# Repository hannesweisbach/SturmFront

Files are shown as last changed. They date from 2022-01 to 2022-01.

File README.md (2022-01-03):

# SturmFront

SturmFront is a DIY fan-controller for indoor sports, which adjusts fan speed according to your current heart rate.

Commercially available is the Wahoo® KICKR Headwind, which has an integrated fan and regulates fan speed according to your power output. Keith Wakeham developed an open-source DIY fan controller named [Maelstom](https://github.com/kwakeham/Maelstrom). Maelstrom also adjusts fan speed according to your power output.

I developed SturmFront independently. A project description is also available: [https://hannesweisbach.github.io/SturmFront/](https://hannesweisbach.github.io/SturmFront/)

## Software used

I used KiCAD as EDA-tool. The controller is based on the Nordic Semiconductor [NRF52832 SoC](https://www.nordicsemi.com/products/nrf52832). I used the [NRF5 SDK 17.1.0](https://www.nordicsemi.com/Products/Development-software/nrf5-sdk/download) in conjuction with the [S332 softdevice](https://www.nordicsemi.com/Products/Development-software/s332-ant) to provide ANT+ and BLE connectivity.

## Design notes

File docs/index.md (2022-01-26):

## SturmFront

SturmFront is a DIY fan-controller for indoor sports, which adjusts fan speed according to your current heart rate.

I use while riding Zwift. The advantages:

* **Never forget to turn on your fan.** SturmFront turns on your fan automatically.
* **Never freeze your butt off during warming up.** SturmFront adjusts the fan speed to your current heart rate. Low heart rate means the fan spins slowly or is even off.
* **Auto-adjusts during the ride.** No weird acrobatics during a ride or race to adjust your fan speed. Your fan already has adjustable speed, but it is almost out of reach? You have to lean awkwardly towards your fan, risking falling off your bike?
* **Never freeze during cooldown.** Ride, race or workout is over? Especially in autumn or winter I was freezing if my fan was still going full blast.

## Alternatives

I developed SturmFront as a low-cost, DIY-version of the well-known Wahoo® KICKR Headwind. In contrast to the KICKR Headwind, SturmFront does not have an integrated fan, but can be thought of like a smart plug, but instead of WiFi it uses ANT+ and instead of simply on/off-control SturmFront offers adjustable power output. This allows SturmFront to turn any fan into a smart fan.
Keith Wakeham developed also a DIY fan controller named [Maelstom](https://github.com/kwakeham/Maelstrom).

## Function

A short, probably not complete description of how SturmFront works.

### Hardware

As basis for SturmFront I used a second-hand WiFi-enabled smart socket from the local classifieds. It cost me only 2,50€ and I got a living room suitable enclosure as well as the proper power socket connectors:

<p align="middle">
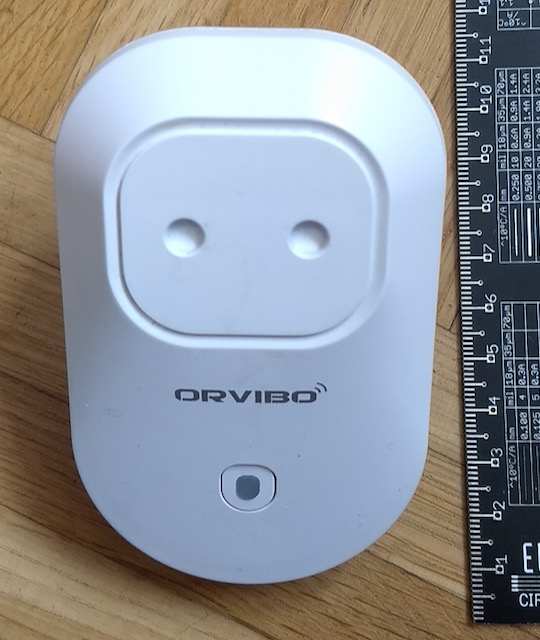
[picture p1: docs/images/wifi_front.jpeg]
Front view of wifi smart socket with CEE 7/4 plug and CEE 7/16 socket.
  
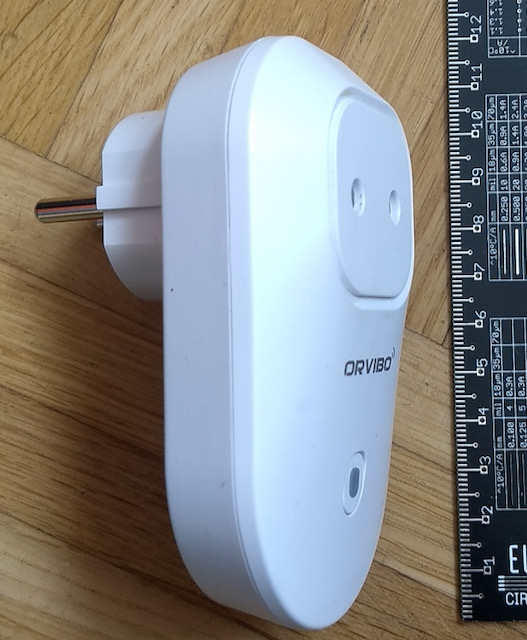
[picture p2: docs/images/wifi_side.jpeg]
Side view of wifi smark socket with CEE 7/4 plug and CEE 7/16 socket.
  
</p>

I also re-used the components from the power supply. I couldn't re-use the SoC and/or WiFi chip, beacuse I needed ANT+ and Bluetooth connectivity. The electro-mechanical relay was also not of any use to me, because I needed phase control to be able to adjust the fan's speed.

The whole circuit consists of a just a few building blocks:
* an SSR with a snubber circuit
* a module with an NRF82832 SoC with ANT+/BLE connectivity
* a zero-crossing circuit to help the NRF control the SSR
* power supply for the NRF

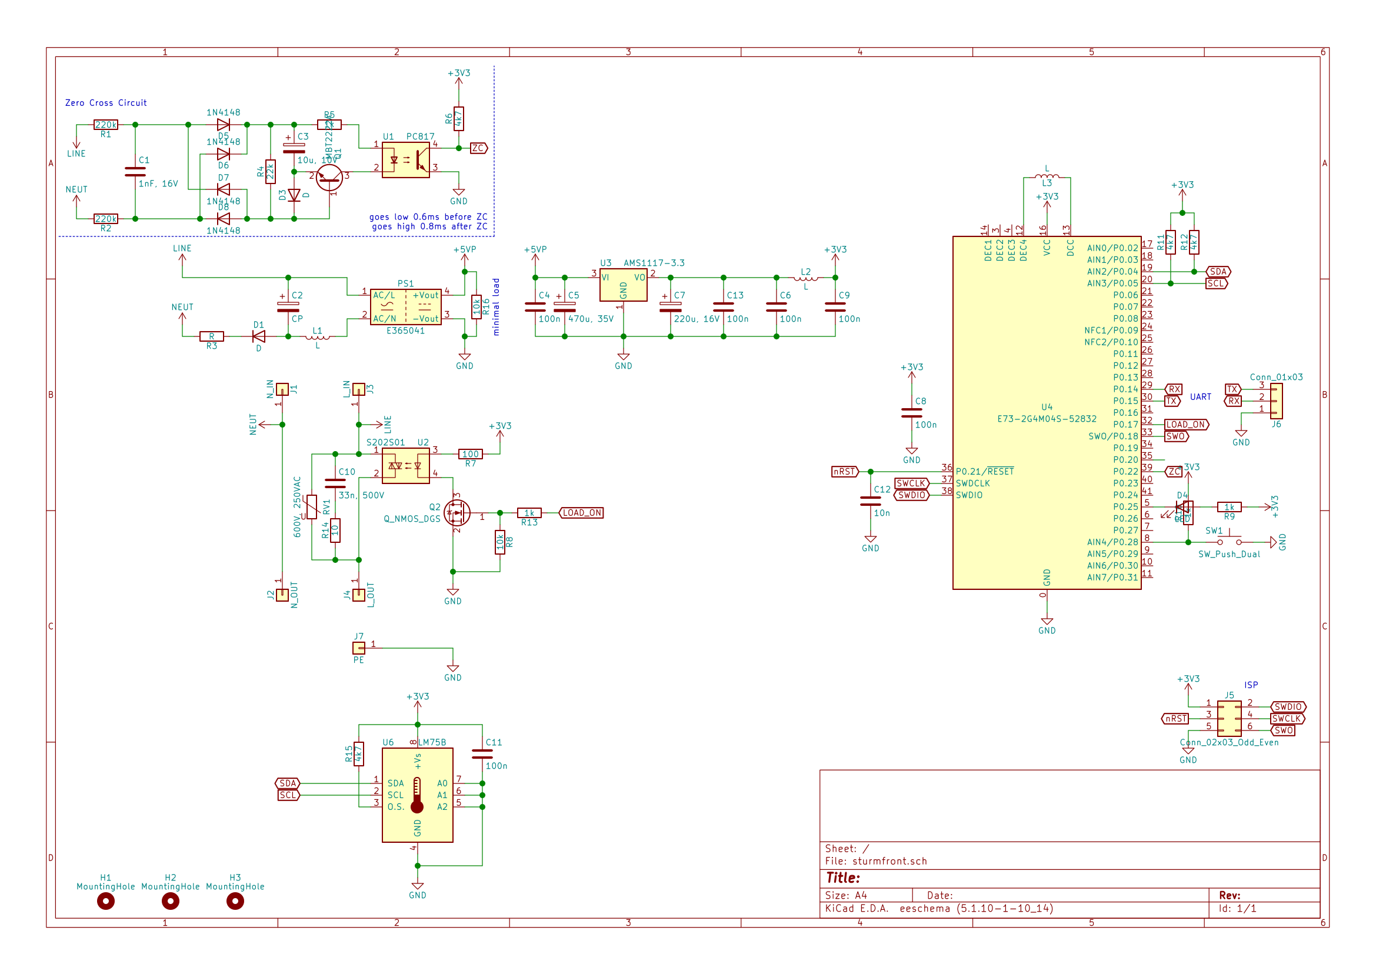
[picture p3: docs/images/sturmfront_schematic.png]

There is a PDF of the schematic under [EDA/sturmfront.pdf](https://github.com/hannesweisbach/SturmFront/blob/master/EDA/sturmfront.pdf).

Both power supply as well as zero cross detection are isolated, which makes this design relatively expensive, but also easier to work with, develop and debug. The Isolated DC/DC-converter as well as the 3.3V LDO are re-used, although I added a PI-filter to the LDO output and the NRF-module is not the best, layout-wise. I also reserved space for an LM75 temperature sensor, but I used to on-chip sensor of the NRF. I figured since the SoC spends most of the time in powerdown anyway the difference from ambient to junction should not be that much (~2K).

Before ordering a manufactured PCB, I isolation-milled an engineering prototype:

<p align="middle">
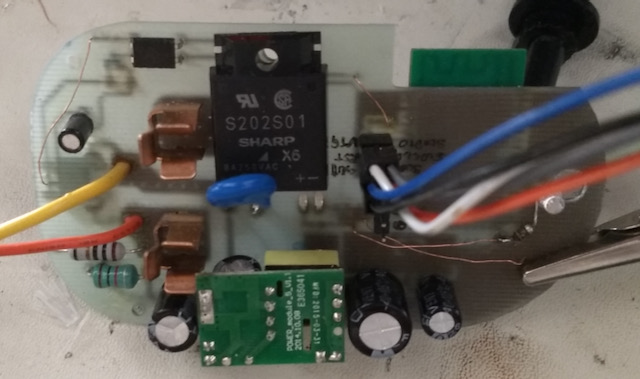
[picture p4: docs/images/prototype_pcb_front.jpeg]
  
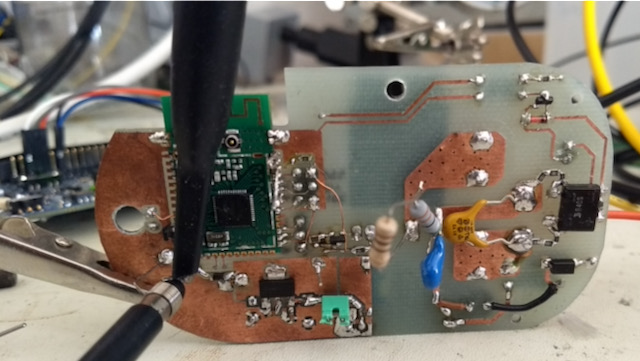
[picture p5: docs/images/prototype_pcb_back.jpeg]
  
</p>

Since the PCB is oddly-shaped with large radii all around plus a button, LED and screw holes all of whose locations have to match with the case, having a prototype allowed me to check all dimensions before ordering as well as to check if all components would still fit in the case height-wise. I was also able to check for errors and improvements in the PCB design. Lastly, I was able to polish the firmware before the final boards arrived.

<p align="middle">
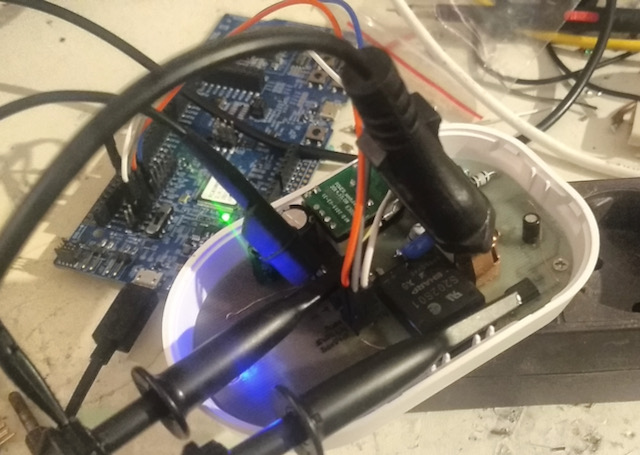
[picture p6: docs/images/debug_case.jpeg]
Isolation milled engineering prototype PCB in smart wifi plug case with oscilloscope probes and debug adapter attached.
  
</p>

Note that the outlet in the picture is not connected to mains but to an isolation transformer for testing.

Making a prototype turned out to be a good decision, since I found multiple errors in the PCB which I had fixed for the final, professionally manufactured PCB. I still managed to sneak a few issues in the final PCB. For example, the silkscreen of the pinout labels of the ISP-connector are hidden underneath the SSR. 😅

<p align="middle">
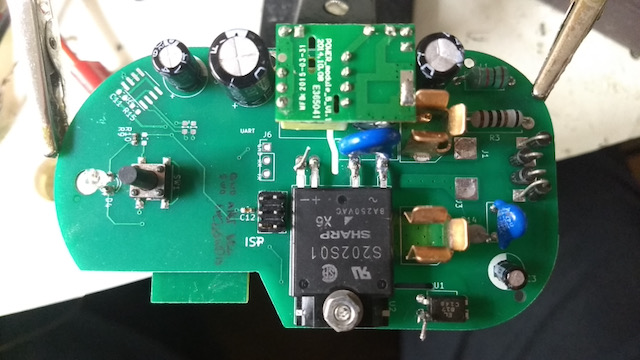
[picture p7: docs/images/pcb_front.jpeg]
  
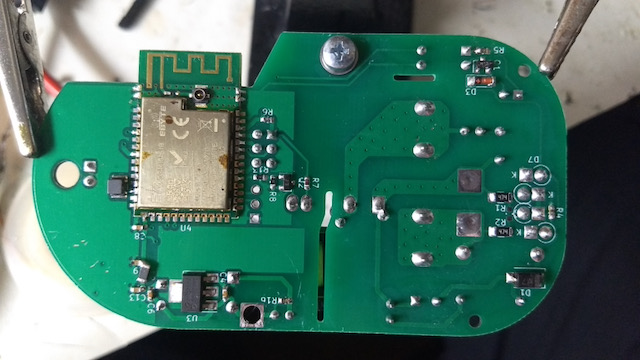
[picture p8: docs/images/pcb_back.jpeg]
  
</p>

### Software

During development and testing of SturmFront it soon became obvious to me that speed control linearly proportinal to heart rate is insufficient.
- First, I added a temperature input to the control software to compensate for colder air temperatures in winter and/or when my window is open. Temperature can be adjusted 5˚K intervals.
- Second, instead of linearly mapping the heart rate to control the SSR, fan speed can now be adjusted 5 bpm increments.

SturmFront uses bilinear mapping to interpolate between 5˚K and 5 bpm values.

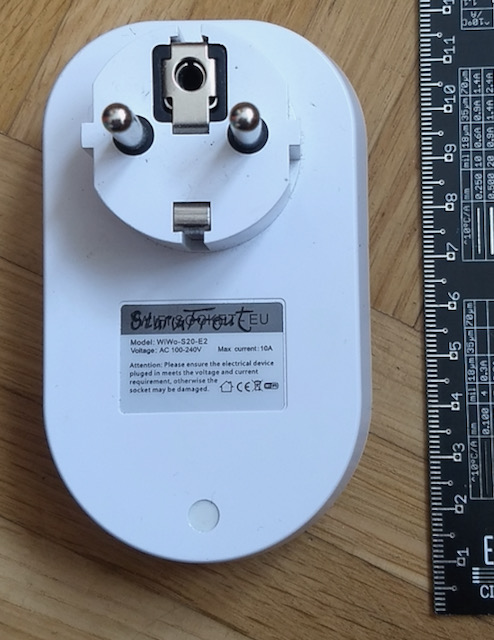
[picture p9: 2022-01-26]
docs/images/wifi_back.jpeg

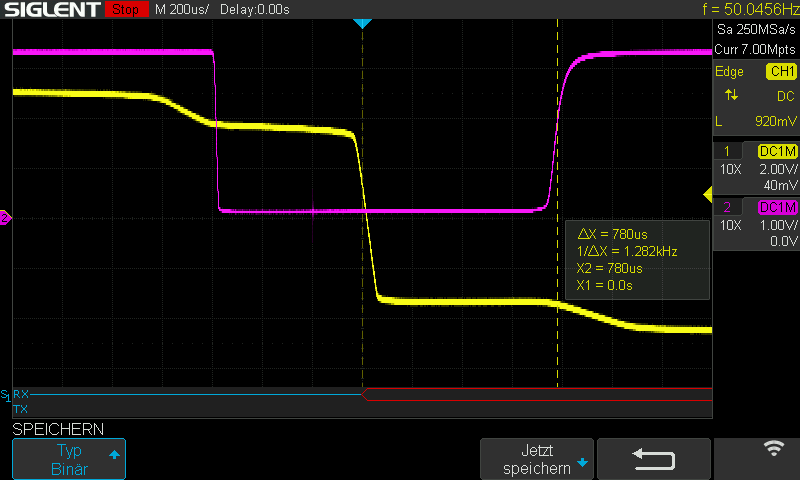
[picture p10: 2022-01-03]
EDA/ZeroCross-2.png

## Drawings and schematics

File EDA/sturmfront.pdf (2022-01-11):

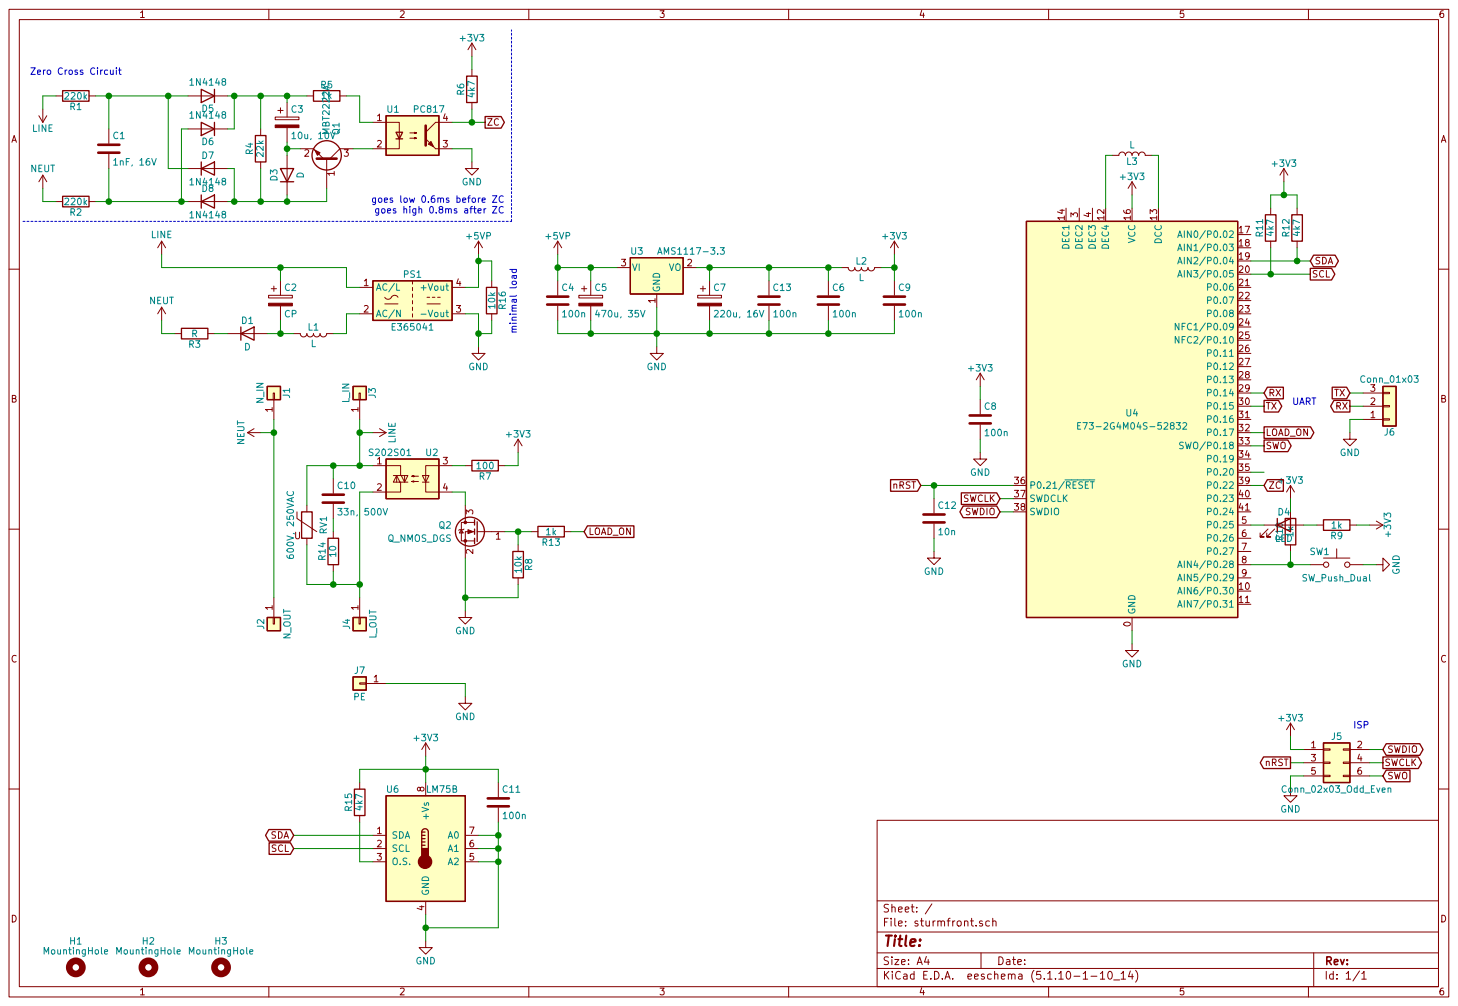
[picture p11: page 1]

goes low 0.6ms before ZC
goes high 0.8ms after ZC minimal load

3 P0.15 30 P0.16 31 P0.17 32 SWO/P0.18 33 P0.19 34 P0.20 35 P0.21/RESET 36 SWDCLK 37 SWDIO 38 P0.22 39 DEC3

Id: 1/1 Title: File: sturmfront.sch Sheet: /

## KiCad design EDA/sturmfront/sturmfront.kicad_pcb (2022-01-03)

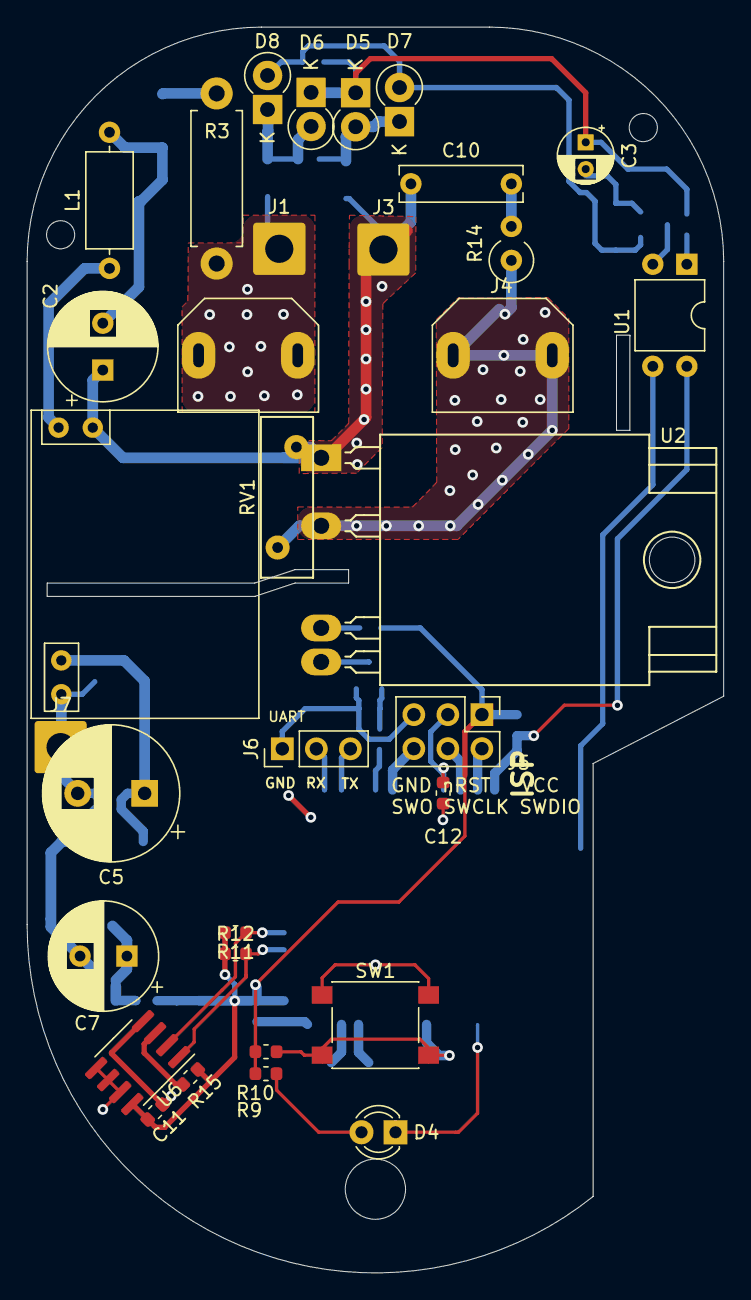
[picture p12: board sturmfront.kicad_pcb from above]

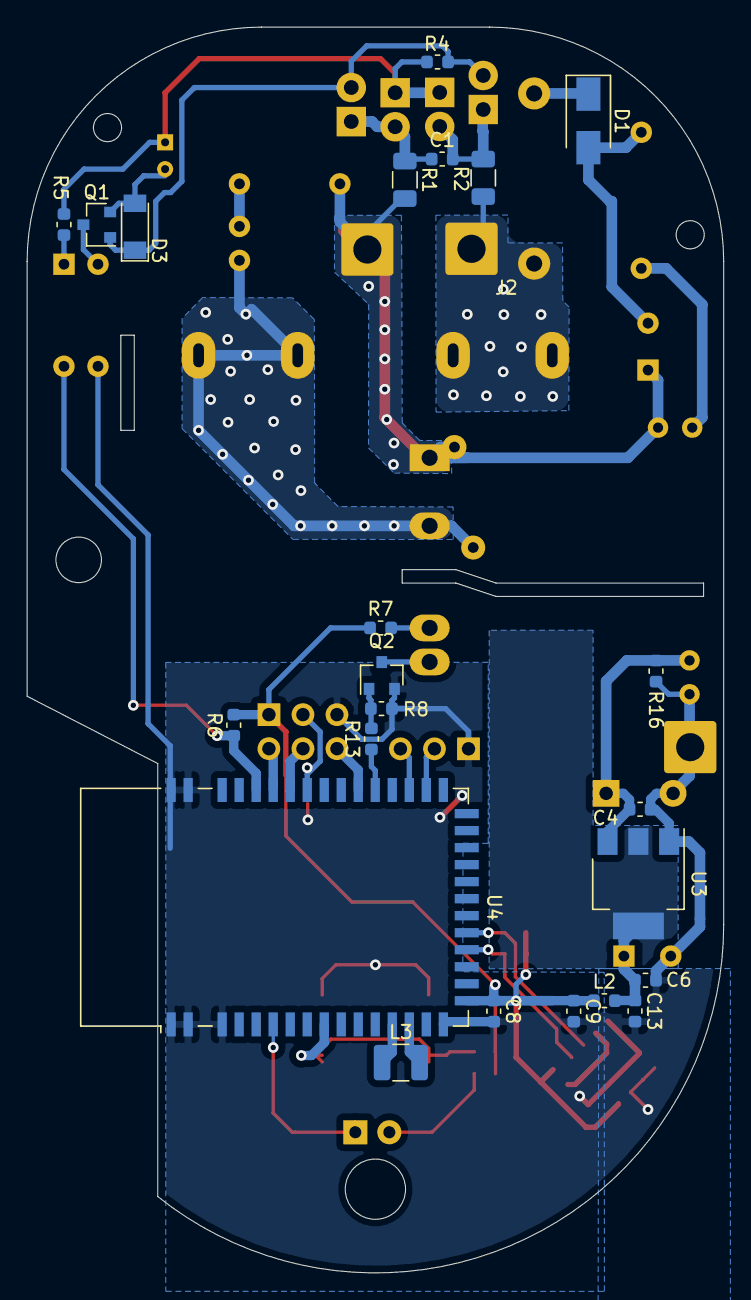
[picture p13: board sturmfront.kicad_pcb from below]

Board: 2 copper layers, 52.0 x 93.0 mm, 59 parts (23 on the bottom side), 37 nets.

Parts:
C1: 1nF, 16V; C_0603_1608Metric
C2: CP; CP_Radial_D8.0mm_P3.50mm
C3: 10u, 10V; CP_Radial_D4.0mm_P2.00mm
C4, C6, C8, C9, C11, C13: 100n; C_0603_1608Metric
C5: 470u, 35V; CP_Radial_D10.0mm_P5.00mm
C7: 220u, 16V; CP_Radial_D8.0mm_P3.50mm
C10: 33n, 500V; C_Rect_L9.0mm_W2.5mm_P7.50mm_MKT
C12: 10n; C_0603_1608Metric
D1: D; D_SMA
D3: D; D_MiniMELF
D4: LED; LED_D3.0mm_Clear
D5, D6, D7, D8: 1N4148; D_DO-41_SOD81_P2.54mm_Vertical_KathodeUp
H1: MountingHole; MountingHole_4.5mm
H2, H3: MountingHole; MountingHole_2.1mm
J1: N_IN; SolderWire-1.5sqmm_1x01_D1.7mm_OD3.9mm
J2: N_OUT; PowerSocket
J3: L_IN; SolderWire-1.5sqmm_1x01_D1.7mm_OD3.9mm
J4: L_OUT; PowerSocket
J5: Conn_02x03_Odd_Even; PinHeader_2x03_P2.54mm_Vertical
J6: Conn_01x03; PinHeader_1x03_P2.54mm_Vertical
J7: PE; SolderWire-1.5sqmm_1x01_D1.7mm_OD3.9mm
L1: L; L_Axial_L7.0mm_D3.3mm_P10.16mm_Horizontal_Fastron_MICC
L2: L; L_0603_1608Metric
L3: L; L_1210_3225Metric
PS1: E365041; DCDC
Q1: MBT2222A; SOT-23
Q2: Q_NMOS_DGS; SOT-23
R1, R2: 220k; R_1206_3216Metric
R3: R; R_Axial_DIN0411_L9.9mm_D3.6mm_P12.70mm_Horizontal
R4: 22k; R_0603_1608Metric
R5, R9, R10, R13: 1k; R_0603_1608Metric
R6, R11, R12, R15: 4k7; R_0603_1608Metric
R7: 100; R_0603_1608Metric
R8, R16: 10k; R_0603_1608Metric
R14: 10; R_Axial_DIN0309_L9.0mm_D3.2mm_P2.54mm_Vertical
RV1: 600V, 250VAC; RV_Disc_D12mm_W3.9mm_P7.5mm
SW1: SW_Push_Dual; SW_Push_1P1T_NO_6x6mm_H9.5mm
U1: PC817; DIP-4_W7.62mm
U2: S202S01; SIP4_Sharp-SSR_P7.62mm_Angled
U3: AMS1117-3.3; SOT-223-3_TabPin2
U4: E73-2G4M04S-52832; E73-2G4M04S
U6: LM75B; SOIC-8_3.9x4.9mm_P1.27mm

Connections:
+3V3: C8.1, C9.1, C11.1, J5.1, L2.1, R6.2, R7.1, R9.1, R10.2, R11.2, R12.2, R15.2, U4.16, U6.8
+5VP: C4.1, C5.1, PS1.4, R16.1, U3.3
GND: C4.2, C5.2, C6.2, C7.2, C8.2, C9.2, C11.2, C12.2, C13.2, J5.5, J6.1, J7.1, PS1.3, Q2.2, R8.2, R16.2, SW1.1, U1.3, U3.1, U4.0, U4.1, U4.2, U4.15, U4.42, U4.43, U6.4, U6.5, U6.6, U6.7
LINE: C2.1, C10.1, J3.1, PS1.1, R1.2, RV1.1, U2.1
LOAD_ON: R13.1, U4.32
NEUT: J1.1, J2.1, R2.2, R3.2
unnamed: C1.1, D5.2, D7.1, R1.1
unnamed: C1.2, D6.2, D8.1, R2.1
unnamed: C2.2, D1.2, L1.2
unnamed: C3.1, D5.1, D6.1, R4.2, R5.1
unnamed: C3.2, D3.2, Q1.2
unnamed: C10.2, R14.2
unnamed: C6.1, C7.1, C13.1, L2.2, U3.2
unnamed: D1.1, R3.1
unnamed: D3.1, D7.2, D8.2, Q1.1, R4.1
unnamed: D4.1, U4.5
unnamed: D4.2, R9.2
unnamed: J4.1, R14.1, RV1.2, U2.2
unnamed: L1.1, PS1.2
unnamed: L3.1, U4.12
unnamed: L3.2, U4.13
unnamed: Q1.3, U1.2
unnamed: Q2.1, R8.1, R13.2
unnamed: Q2.3, U2.4
unnamed: R5.2, U1.1
unnamed: R7.2, U2.3
unnamed: R10.1, SW1.2, U4.8
unnamed: R15.1, U6.3
RX: J6.2, U4.29
SCL: R11.1, U4.20, U6.2
SDA: R12.1, U4.19, U6.1
SWCLK: J5.4, U4.37
SWDIO: J5.2, U4.38
SWO: J5.6, U4.33
TX: J6.3, U4.30
ZC: R6.1, U1.4, U4.39
nRST: C12.1, J5.3, U4.36

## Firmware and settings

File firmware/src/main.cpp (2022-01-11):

/**
 * Copyright (c) 2013 - 2021, Nordic Semiconductor ASA
 *
 * All rights reserved.
 *
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
 * 3. Neither the name of Nordic Semiconductor ASA nor the names of its
 *    contributors may be used to endorse or promote products derived from this
 *    software without specific prior written permission.
 *
 * 4. This software, with or without modification, must only be used with a
 *    Nordic Semiconductor ASA integrated circuit.
 *
 * 5. Any software provided in binary form under this license must not be reverse
 *    engineered, decompiled, modified and/or disassembled.
 *
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
 */
/** @file
 *
 * @defgroup ble_sdk_app_ant_hrs_main main.c
 * @{
 * @ingroup ble_sdk_app_ant_hrs
 * @brief HRM sample application using both BLE and ANT.
 *
 * The application uses the BLE Heart Rate Service (and also the Device Information
 * services), and the ANT HRM RX profile.
 *
 * It will open a receive channel which will connect to an ANT HRM TX profile device when the
 * application starts. The received data will be propagated to a BLE central through the
 * BLE Heart Rate Service.
 *
 * The ANT HRM TX profile device simulator SDK application
 * (Board\pca10003\ant\ant_hrm\hrm_tx_buttons) can be used as a peer ANT device. By changing
 * ANT_HRMRX_NETWORK_KEY to the ANT+ Network Key, the application will instead be able to connect to
 * an ANT heart rate belt.
 *
 * @note The ANT+ Network Key is available for ANT+ Adopters. Please refer to
 *       http://thisisant.com to become an ANT+ Adopter and access the key.
 *
 * @note This application is based on the BLE Heart Rate Service Sample Application
 *       (Board\nrf6310\ble\ble_app_hrs). Please refer to this application for additional
 *       documentation.
 */

#include <atomic>
#include <stdint.h>
#include <string.h>
#include <cmath>
#include <algorithm>

#include "nrf.h"
#include "nrf_gpio.h"

#include <nrf_dfu_ble_svci_bond_sharing.h>
#include <nrf_svci_async_function.h>
#include <nrf_svci_async_handler.h>


#include "nordic_common.h"
#include "app_error.h"
#include "app_timer.h"
#include "ble.h"
#include "ble_hci.h"
#include "ble_conn_state.h"
#include "ble_conn_params.h"
#include "ble_srv_common.h"
#include "ble_advdata.h"
#include "ble_hrs.h"
#include "ble_dis.h"
#include <ble_dfu.h>
#include "bsp.h"
#include "fds.h"
#include "led_softblink.h"
#include "peer_manager.h"
#include "peer_manager_handler.h"
#include "sensorsim.h"
#include "nrf_ble_gatt.h"
#include "nrfx_ppi.h"
#include "nrfx_timer.h"
#include "nrfx_gpiote.h"
#include "nrf_sdh.h"
#include <nrf_sdm.h>
#include "nrf_sdh_ble.h"
#include "nrf_sdh_ant.h"
#include "nrf_sdh_soc.h"
#include "nrf_ble_qwr.h"
#include "nrf_pwr_mgmt.h"
#include <nrf_power.h>
#include <nrf_bootloader_info.h>

#include <ant_error.h>
#include <ant_search_config.h>
#include <ant_key_manager.h>
#include <ant_hrm.h>
#include <ant_parameters.h>
#include <ant_interface.h>


#include "nrf_log.h"
#include "nrf_log_ctrl.h"
#include "nrf_log_default_backends.h"

#include "configuration.h"

#define WAKEUP_BUTTON_ID                0                                            /**< Button used to wake up the application. */
#define BOND_DELETE_ALL_BUTTON_ID       1                                            /**< Button used for deleting all bonded centrals during startup. */

#define DEVICE_NAME                     "SturmFront"                                 /**< Name of device. Will be included in the advertising data. */
#define MANUFACTURER_NAME               "hannesweisbach"                        /**< Manufacturer. Will be passed to Device Information Service. */
#define APP_ADV_INTERVAL                40                                           /**< The advertising interval (in units of 0.625 ms. This value corresponds to 25 ms). */
#define APP_ADV_DURATION                0                                           /**< The advertising duration in units of 10ms; 0 for indefinite */

#define APP_BLE_CONN_CFG_TAG            1                                            /**< A tag that refers to the BLE stack configuration we set with @ref sd_ble_cfg_set. Default tag is @ref BLE_CONN_CFG_TAG_DEFAULT. */

#define IS_SRVC_CHANGED_CHARACT_PRESENT 0                                            /**< Whether or not to include the service_changed characteristic. If not enabled, the server's database cannot be changed for the lifetime of the device */

#define CONN_INTERVAL_BASE              80                                           /**< Definition of 100 ms, when 1 unit is 1.25 ms. */
#define SECOND_10_MS_UNITS              100                                          /**< Definition of 1 second, when 1 unit is 10 ms. */
#define MIN_CONN_INTERVAL               (CONN_INTERVAL_BASE / 2)                     /**< Minimum acceptable connection interval (50 ms), Connection interval uses 1.25 ms units. */
#define MAX_CONN_INTERVAL               (CONN_INTERVAL_BASE)                         /**< Maximum acceptable connection interval (100 ms), Connection interval uses 1.25 ms units. */
#define SLAVE_LATENCY                   0                                            /**< Slave latency. */
#define CONN_SUP_TIMEOUT                (4 * SECOND_10_MS_UNITS)                     /**< Connection supervisory timeout (4 seconds), Supervision Timeout uses 10 ms units. */

#define FIRST_CONN_PARAMS_UPDATE_DELAY  APP_TIMER_TICKS(5000)                        /**< Time from initiating event (connect or start of notification) to first time sd_ble_gap_conn_param_update is called (5 seconds). */
#define NEXT_CONN_PARAMS_UPDATE_DELAY   APP_TIMER_TICKS(30000)                       /**< Time between each call to sd_ble_gap_conn_param_update after the first call (30 seconds). */
#define MAX_CONN_PARAMS_UPDATE_COUNT    3                                            /**< Number of attempts before giving up the connection parameter negotiation. */

#define SEC_PARAM_TIMEOUT               30                                           /**< Timeout for Pairing Request or Security Request (in seconds). */
#define SEC_PARAM_BOND                  1                                            /**< Perform bonding. */
#define SEC_PARAM_MITM                  0                                            /**< Man In The Middle protection not required. */
#define SEC_PARAM_IO_CAPABILITIES       BLE_GAP_IO_CAPS_NONE                         /**< No I/O capabilities. */
#define SEC_PARAM_OOB                   0                                            /**< Out Of Band data not available. */
#define SEC_PARAM_MIN_KEY_SIZE          7                                            /**< Minimum encryption key size. */
#define SEC_PARAM_MAX_KEY_SIZE          16                                           /**< Maximum encryption key size. */

#define DEAD_BEEF                       0xDEADBEEF                                   /**< Value used as error code on stack dump, can be used to identify stack location on stack unwind. */

#define ANT_HRMRX_TRANS_TYPE            0                                            /**< Transmission Type. */
#define ANTPLUS_NETWORK_NUMBER          0                                            /**< Network number. */


static volatile uint16_t                m_conn_handle = BLE_CONN_HANDLE_INVALID;     /**< Handle of the current connection. */
static uint8_t                          m_adv_handle;                                /**< Advertising handle. */
BLE_HRS_DEF(m_hrs);                                                                  /**< Heart rate service instance. */
NRF_BLE_QWR_DEF(m_qwr);                                                              /**< Context for the Queued Write module.*/
NRF_BLE_GATT_DEF(m_gatt);                                                            /**< GATT module instance. */

static bool entering_dfu{false};

static ble_sfc_t m_sfc;
NRF_SDH_BLE_OBSERVER(m_sfc_obs, BLE_SFC_BLE_OBSERVER_PRIO, ble_sfc_on_ble_evt,
                     &m_sfc);

NRF_SDH_STATE_OBSERVER(m_buttonless_dfu_state_obs, 0) = {
    .handler =
        [](nrf_sdh_state_evt_t state, void *) {
          if (state == NRF_SDH_EVT_STATE_DISABLED) {
            // Softdevice was disabled before going into reset. Inform
            // bootloader to skip CRC on next boot.
            nrf_power_gpregret2_set(BOOTLOADER_DFU_SKIP_CRC);

            // Go to system off.
            nrf_pwr_mgmt_shutdown(NRF_PWR_MGMT_SHUTDOWN_GOTO_SYSOFF);
          }
        },
};

class ZC {
#if 0
  // simulated ZC pin input
  static const int AC_LINE_ZC_PIN = 23;
#else
  // actual ZC pin input
  static const int AC_LINE_ZC_PIN = 22;
#endif

public:
  void setup() {
    nrfx_gpiote_in_config_t zc = {.sense = NRF_GPIOTE_POLARITY_HITOLO,
                                  .pull = NRF_GPIO_PIN_PULLUP,
                                  .is_watcher = false,
                                  .hi_accuracy = true,
                                  .skip_gpio_setup = false};
    APP_ERROR_CHECK(nrfx_gpiote_in_init(AC_LINE_ZC_PIN, &zc, NULL));
  }

  void begin() { nrfx_gpiote_in_event_enable(AC_LINE_ZC_PIN, false); }

  auto get_zc_eep() const {
    return nrfx_gpiote_in_event_addr_get(AC_LINE_ZC_PIN);
  }
} zc;

class FrequencyCounter {
  nrfx_timer_t zc_counter = NRFX_TIMER_INSTANCE(3);
  nrfx_timer_t timer = NRFX_TIMER_INSTANCE(4);

  // measure ~1s
  static const int measurement_periods = 110;

  uint32_t measured_line_period_us = 0;
  float measured_line_freq_hz = 0.0;

public:
  void init(uint32_t eep) {
    nrfx_timer_config_t counter_cfg{.frequency = NRF_TIMER_FREQ_1MHz,
                                    .mode = NRF_TIMER_MODE_COUNTER,
                                    .bit_width = NRF_TIMER_BIT_WIDTH_8,
                                    .interrupt_priority =
                                        NRFX_TIMER_DEFAULT_CONFIG_IRQ_PRIORITY,
                                    .p_context = this};
    APP_ERROR_CHECK(nrfx_timer_init(
        &zc_counter, &counter_cfg, [](nrf_timer_event_t evt, void *context) {
          auto ctr = reinterpret_cast<FrequencyCounter *>(context);
          ctr->measured_line_period_us =
              nrfx_timer_capture_get(&ctr->timer, NRF_TIMER_CC_CHANNEL0) * 2 /
              (ctr->measurement_periods);
          ctr->measured_line_freq_hz =
              1000.0f * 1000.0f /
              static_cast<float>(ctr->measured_line_period_us);

          if (0) {
            const uint32_t ticks =
                nrfx_timer_capture_get(&ctr->timer, NRF_TIMER_CC_CHANNEL0);

            NRF_LOG_INFO("Ticks: %u %u / " NRF_LOG_FLOAT_MARKER, ticks,
                         ctr->line_period_us(),
                         NRF_LOG_FLOAT(ctr->line_freq()));
          }
        }));

    static_assert(measurement_periods <= UINT8_MAX,
                  "increase bit-width of counter");
    nrfx_timer_extended_compare(&zc_counter, NRF_TIMER_CC_CHANNEL0,
                                measurement_periods,
                                NRF_TIMER_SHORT_COMPARE0_CLEAR_MASK, true);

    nrfx_timer_config_t timer_cfg = NRFX_TIMER_DEFAULT_CONFIG;
    APP_ERROR_CHECK(nrfx_timer_init(&timer, &timer_cfg, NULL));

    /* channel from ZC input pin to counter */
    nrf_ppi_channel_t zc_events;
    APP_ERROR_CHECK(nrfx_ppi_channel_alloc(&zc_events));
    APP_ERROR_CHECK(nrfx_ppi_channel_assign(
        zc_events, eep,
        nrfx_timer_task_address_get(&zc_counter, NRF_TIMER_TASK_COUNT)));

    /* channel from counter compare to timer stop */
    nrf_ppi_channel_t timer_stop;
    APP_ERROR_CHECK(nrfx_ppi_channel_alloc(&timer_stop));
    APP_ERROR_CHECK(nrfx_ppi_channel_assign(
        timer_stop,
        nrfx_timer_event_address_get(&zc_counter, NRF_TIMER_EVENT_COMPARE0),
        nrfx_timer_task_address_get(&timer, NRF_TIMER_TASK_CAPTURE0)));
    /* also clear timer on counter compare */
    APP_ERROR_CHECK(nrfx_ppi_channel_fork_assign(
        timer_stop, nrfx_timer_task_address_get(&timer, NRF_TIMER_TASK_CLEAR)));

    APP_ERROR_CHECK(nrfx_ppi_channel_enable(zc_events));
    APP_ERROR_CHECK(nrfx_ppi_channel_enable(timer_stop));

    nrfx_timer_enable(&zc_counter);
    nrfx_timer_enable(&timer);
  }

  uint32_t line_period_us() { return measured_line_period_us; }
  float line_freq() { return measured_line_freq_hz; }
} line_freq_detect;

class Fan {
  class SSR {
    // SSR pin output
    static const int SSR_PIN = 17;
    static const unsigned PRE_ZC_US = 550;

    ZC zc;

    nrfx_timer_t delay_timer = NRFX_TIMER_INSTANCE(2);
    bool enabled_ = false;

    unsigned map_duty_to_us(unsigned pct) {
      const unsigned half_cycle_us = line_freq_detect.line_period_us() / 2;
      const unsigned hold_off_pct =
          (half_cycle_us * 100) - (half_cycle_us * pct);

      return hold_off_pct / 100;
    }

    void ssr_configure_ticks(const uint32_t ticks) {
      nrfx_timer_compare(&delay_timer, NRF_TIMER_CC_CHANNEL0, ticks, false);
    }

  public:
    void setup(const uint32_t zc_eep) {
      nrfx_gpiote_out_config_t ssr_config = {
          .action =
              static_cast<nrf_gpiote_polarity_t>(GPIOTE_CONFIG_POLARITY_None),
          .init_state = NRF_GPIOTE_INITIAL_VALUE_LOW,
          .task_pin = true,
      };
      APP_ERROR_CHECK(nrfx_gpiote_out_init(SSR_PIN, &ssr_config));

      nrfx_timer_config_t timer_cfg = NRFX_TIMER_DEFAULT_CONFIG;
      APP_ERROR_CHECK(nrfx_timer_init(&delay_timer, &timer_cfg, NULL));

      nrfx_timer_compare(&delay_timer, NRF_TIMER_CC_CHANNEL0, 0, false);

      // ZC turns SSR off
      // ZC clears delay timer
      // ZC starts delay timer
      // delay timer CC triggers SSR
      // delay timer CC stops delay timer

      nrf_ppi_channel_t timer_ch;
      APP_ERROR_CHECK(nrfx_ppi_channel_alloc(&timer_ch));
      APP_ERROR_CHECK(nrfx_ppi_channel_assign(
          timer_ch, zc_eep,
          nrfx_timer_task_address_get(&delay_timer, NRF_TIMER_TASK_CLEAR)));
      APP_ERROR_CHECK(nrfx_ppi_channel_enable(timer_ch));

      nrf_ppi_channel_t ssr_clr_ch;
      APP_ERROR_CHECK(nrfx_ppi_channel_alloc(&ssr_clr_ch));
      APP_ERROR_CHECK(nrfx_ppi_channel_assign(
          ssr_clr_ch, zc_eep, nrfx_gpiote_clr_task_addr_get(SSR_PIN)));
      APP_ERROR_CHECK(nrfx_ppi_channel_enable(ssr_clr_ch));

      nrf_ppi_channel_t ssr_set_ch;
      APP_ERROR_CHECK(nrfx_ppi_channel_alloc(&ssr_set_ch));
      APP_ERROR_CHECK(nrfx_ppi_channel_assign(
          ssr_set_ch,
          nrfx_timer_event_address_get(&delay_timer, NRF_TIMER_EVENT_COMPARE0),
          nrfx_gpiote_set_task_addr_get(SSR_PIN)));
      APP_ERROR_CHECK(nrfx_ppi_channel_enable(ssr_set_ch));

      nrfx_timer_enable(&delay_timer);
    }

    void enable() {
      if (enabled_) {
        return;
      }

      NRF_LOG_INFO("SSR Enabled");

      nrfx_gpiote_out_task_enable(SSR_PIN);

      enabled_ = true;
      // m_sfc.update_ssr_state(enabled_);
    }

    void disable() {
      if (disabled()) {
        return;
      }

      NRF_LOG_INFO("Disabling SSR");

      nrfx_gpiote_out_task_disable(SSR_PIN);
      nrfx_gpiote_out_clear(SSR_PIN);

      enabled_ = false;
      // m_sfc.update_ssr_state(enabled_);
    }

    void set_percent(const uint8_t duty, bool do_enable = true) {
      if (do_enable && disabled()) {
        enable();
      }

      const unsigned us = map_duty_to_us(duty);
      const unsigned ticks =
          nrfx_timer_us_to_ticks(&delay_timer, us + PRE_ZC_US);

      if (duty > 0 && duty < 100) {
        NRF_LOG_RAW_INFO("/r:%u/%d us\n", duty, ticks);
        ssr_configure_ticks(ticks);
        if (enabled()) {
          nrfx_gpiote_out_task_enable(SSR_PIN);
        }
      } else if (duty <= 0 || disabled()) {
        nrfx_gpiote_out_task_disable(SSR_PIN);
        nrfx_gpiote_out_clear(SSR_PIN);
      } else if (duty >= 100) {
        nrfx_gpiote_out_task_disable(SSR_PIN);
        nrfx_gpiote_out_set(SSR_PIN);
      }
    }

    bool enabled() const { return enabled_; }
    bool disabled() const { return !enabled_; }

  } ssr;

  unsigned hr_ = 0;
  unsigned temperature_ = 0;
  enum class State { Off, Spinup, On } state = State::Off;
  static const constexpr int spinupDelay = 5;
  int spinCount = 0;

  unsigned remap_min_duty(const unsigned duty, enum State state) {
    const auto min_duty = (state == State::On) ? m_sfc.setting(MIN_DUTY_WARM)
                                               : m_sfc.setting(MIN_DUTY_COLD);
    return duty * (100 - min_duty) / 100 + min_duty;
  }

public:
  void setup(const unsigned eep) { ssr.setup(eep); }

  void set_duty(const uint8_t duty, const bool debug = false) {
    if (debug) {
      // spin up again, when exiting debug mode
      state = State::Off;
      ssr.set_percent(duty);
      return;
    }

    const bool on = duty > 0;

    NRF_LOG_RAW_INFO("/s:%d", state);

    switch (state) {
    case State::Off:
      if (on) {
        state = State::Spinup;
        spinCount = 0;
      }
      break;
    case State::Spinup:
      if (spinCount >= spinupDelay) {
        state = State::On;
      }
      ++spinCount;
      break;
    case State::On:
      break;
    }

    if (state != State::Off && !on) {
      state = State::Off;
    }

    if (state == State::Off) {
      ssr.disable();
      NRF_LOG_RAW_INFO("\n");
    } else {
      ssr.set_percent(remap_min_duty(duty, state));
    }
  }

  void hr(const unsigned hr) { hr_ = hr; }
  void temperature(const unsigned temp) { temperature_ = temp; }

  void on() { ssr.set_percent(100); }
  void off() {
    ssr.set_percent(0, false);
    ssr.disable();
    state = State::Off;
  }
} fan;

#define MY_APP_TIMER_DEF(timer_id)                                             \
  NRF_LOG_INSTANCE_REGISTER(                                                   \
      APP_TIMER_LOG_NAME, timer_id, APP_TIMER_CONFIG_INFO_COLOR,               \
      APP_TIMER_CONFIG_DEBUG_COLOR, APP_TIMER_CONFIG_INITIAL_LOG_LEVEL,        \
      APP_TIMER_CONFIG_LOG_ENABLED ? APP_TIMER_CONFIG_LOG_LEVEL                \
                                   : NRF_LOG_SEVERITY_NONE);                   \
  app_timer_t CONCAT_2(timer_id, _data) = {                                    \
      .end_val = APP_TIMER_IDLE_VAL,                                           \
      NRF_LOG_INSTANCE_PTR_INIT(p_log, APP_TIMER_LOG_NAME, timer_id)};         \
  const app_timer_id_t timer_id = &CONCAT_2(timer_id, _data)
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
int main(void)
{
    uint32_t err_code;

    err_code = NRF_LOG_INIT(NULL);
    APP_ERROR_CHECK(err_code);

    NRF_LOG_DEFAULT_BACKENDS_INIT();

    // Initialize peripherals
    timers_init();


    err_code = nrfx_gpiote_init();
    APP_ERROR_CHECK(err_code);

    ble_sfc_init_static(&m_sfc);

    err_code = nrf_pwr_mgmt_init();
    APP_ERROR_CHECK(err_code);

    softdevice_setup();

    // FDS initialization
    {
      static std::atomic_bool fds_initialized{false};

      fds_register([](fds_evt_t const *p_evt) {
        switch (p_evt->id) {
        case FDS_EVT_INIT:
          if (p_evt->result == NRF_SUCCESS) {
            fds_initialized = true;
          }
          break;
        case FDS_EVT_GC:
          NRF_LOG_INFO("FDS GC done.");
          break;
        default:
          break;
        }
      });

      APP_ERROR_CHECK(fds_init());
      idle_loop([] { return !fds_initialized.load(); });
      APP_ERROR_CHECK(fds_gc());
    }

    io.init(
        []() {
          app.toggleMode();
          app.tick();
        },
        []() {
          m_sfc.setting(ANT_DEVICE, ANTHRM::ANT_HRMRX_DEVICE_NUMBER_ANY);
          hrm.reconfigure();
        });

    // Initialize Bluetooth stack parameters.
    gatt_init();
    gap_params_init();
    services_init();
    advertising_init();
    conn_params_init();

    hrm.setup(m_sfc.setting(ANT_DEVICE));

#ifdef BONDING_ENABLE
    bool erase_bonds = bsp_button_is_pressed(BOND_DELETE_ALL_BUTTON_ID);
    peer_manager_init(erase_bonds);
    if (erase_bonds == true)
    {
        NRF_LOG_INFO("Bonds erased!");
    }
#endif // BONDING_ENABLE

    zc.setup();

    line_freq_detect.init(zc.get_zc_eep());
    fan.setup(zc.get_zc_eep());
    //ac_line_simulation_setup(&m_sfc);


    NRF_LOG_INFO("SF ready.");
    ant_and_adv_start();

    zc.begin();

    // Start application timer tick.
    app.init();

    idle_loop([] { return true; });
}

/**
 * @}
 */

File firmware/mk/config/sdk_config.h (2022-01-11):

/**
 * Copyright (c) 2017 - 2021, Nordic Semiconductor ASA
 *
 * All rights reserved.
 *
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
 * 3. Neither the name of Nordic Semiconductor ASA nor the names of its
 *    contributors may be used to endorse or promote products derived from this
 *    software without specific prior written permission.
 *
 * 4. This software, with or without modification, must only be used with a
 *    Nordic Semiconductor ASA integrated circuit.
 *
 * 5. Any software provided in binary form under this license must not be reverse
 *    engineered, decompiled, modified and/or disassembled.
 *
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
 */



#ifndef SDK_CONFIG_H
#define SDK_CONFIG_H
// <<< Use Configuration Wizard in Context Menu >>>\n
#ifdef USE_APP_CONFIG
#include "app_config.h"
#endif


// <h> Application 

//==========================================================
// <o> APP_ANT_OBSERVER_PRIO - Application ANT event observer priority. 
#ifndef APP_ANT_OBSERVER_PRIO
#define APP_ANT_OBSERVER_PRIO 2
#endif

// <o> APP_BLE_OBSERVER_PRIO - Application BLE event observer priority. 
#ifndef APP_BLE_OBSERVER_PRIO
#define APP_BLE_OBSERVER_PRIO 0
#endif

// <o> APP_SHUTDOWN_HANDLER_PRIORITY - Application shutdown observer priority. 
#ifndef APP_SHUTDOWN_HANDLER_PRIORITY
#define APP_SHUTDOWN_HANDLER_PRIORITY 1
#endif

// </h> 
//==========================================================

// <h> nRF_ANT 

//==========================================================
// <q> ANT_CHANNEL_CONFIG_ENABLED  - ant_channel_config - ANT common channel configuration
 

#ifndef ANT_CHANNEL_CONFIG_ENABLED
#define ANT_CHANNEL_CONFIG_ENABLED 1
#endif

// <e> ANT_SEARCH_CONFIG_ENABLED - ant_search_config - ANT common search configuration
//==========================================================
#ifndef ANT_SEARCH_CONFIG_ENABLED
#define ANT_SEARCH_CONFIG_ENABLED 1
#endif
// <o> ANT_DEFAULT_LOW_PRIORITY_TIMEOUT - Default low priority search time-out.  <0-255> 


#ifndef ANT_DEFAULT_LOW_PRIORITY_TIMEOUT
#define ANT_DEFAULT_LOW_PRIORITY_TIMEOUT 2
#endif

// <o> ANT_DEFAULT_HIGH_PRIORITY_TIMEOUT - Default high priority search time-out.  <0-255> 


#ifndef ANT_DEFAULT_HIGH_PRIORITY_TIMEOUT
#define ANT_DEFAULT_HIGH_PRIORITY_TIMEOUT 10
#endif

// </e>


// <e> ANT_HRM_ENABLED - ant_hrm - Heart Rate Monitor Profile
//==========================================================
#ifndef ANT_HRM_ENABLED
#define ANT_HRM_ENABLED 1
#endif
// <e> ANT_HRM_LOG_ENABLED - Enables general logging in the module.
//==========================================================
#ifndef ANT_HRM_LOG_ENABLED
#define ANT_HRM_LOG_ENABLED 0
#endif
// <o> ANT_HRM_LOG_LEVEL  - Default Severity level
 
// <0=> Off 
// <1=> Error 
// <2=> Warning 
// <3=> Info 
// <4=> Debug 

#ifndef ANT_HRM_LOG_LEVEL
#define ANT_HRM_LOG_LEVEL 3
#endif

// <o> ANT_HRM_INFO_COLOR  - ANSI escape code prefix.
 
// <0=> Default 
// <1=> Black 
// <2=> Red 
// <3=> Green 
// <4=> Yellow 
// <5=> Blue 
// <6=> Magenta 
// <7=> Cyan 
// <8=> White 

#ifndef ANT_HRM_INFO_COLOR
#define ANT_HRM_INFO_COLOR 0
#endif

// </e>

// <e> ANT_HRM_PAGE_0_LOG_ENABLED - Enables logging of HRM page 0 in the module.
//==========================================================
#ifndef ANT_HRM_PAGE_0_LOG_ENABLED
#define ANT_HRM_PAGE_0_LOG_ENABLED 0
#endif
// <o> ANT_HRM_PAGE_0_LOG_LEVEL  - Default Severity level
 
// <0=> Off 
// <1=> Error 
// <2=> Warning 
// <3=> Info 
// <4=> Debug 

#ifndef ANT_HRM_PAGE_0_LOG_LEVEL
#define ANT_HRM_PAGE_0_LOG_LEVEL 3
#endif

// <o> ANT_HRM_PAGE_0_INFO_COLOR  - ANSI escape code prefix.
 
// <0=> Default 
// <1=> Black 
// <2=> Red 
// <3=> Green 
// <4=> Yellow 
// <5=> Blue 
// <6=> Magenta 
// <7=> Cyan 
// <8=> White 

#ifndef ANT_HRM_PAGE_0_INFO_COLOR
#define ANT_HRM_PAGE_0_INFO_COLOR 0
#endif

// </e>

// <e> ANT_HRM_PAGE_1_LOG_ENABLED - Enables logging of HRM page 1 in the module.
//==========================================================
#ifndef ANT_HRM_PAGE_1_LOG_ENABLED
#define ANT_HRM_PAGE_1_LOG_ENABLED 0
#endif
// <o> ANT_HRM_PAGE_1_LOG_LEVEL  - Default Severity level
 
// <0=> Off 
// <1=> Error 
// <2=> Warning 
// <3=> Info 
// <4=> Debug 

#ifndef ANT_HRM_PAGE_1_LOG_LEVEL
#define ANT_HRM_PAGE_1_LOG_LEVEL 3
#endif

// <o> ANT_HRM_PAGE_1_INFO_COLOR  - ANSI escape code prefix.
 
// <0=> Default 
// <1=> Black 
// <2=> Red 
// <3=> Green 
// <4=> Yellow 
// <5=> Blue 
// <6=> Magenta 
// <7=> Cyan 
// <8=> White 

#ifndef ANT_HRM_PAGE_1_INFO_COLOR
#define ANT_HRM_PAGE_1_INFO_COLOR 0
#endif

// </e>

// <e> ANT_HRM_PAGE_2_LOG_ENABLED - Enables logging of HRM page 2 in the module.
//==========================================================
#ifndef ANT_HRM_PAGE_2_LOG_ENABLED
#define ANT_HRM_PAGE_2_LOG_ENABLED 0
#endif
// <o> ANT_HRM_PAGE_2_LOG_LEVEL  - Default Severity level
 
// <0=> Off 
// <1=> Error 
// <2=> Warning 
// <3=> Info 
// <4=> Debug 

#ifndef ANT_HRM_PAGE_2_LOG_LEVEL
#define ANT_HRM_PAGE_2_LOG_LEVEL 3
#endif

// <o> ANT_HRM_PAGE_2_INFO_COLOR  - ANSI escape code prefix.
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

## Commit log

2022-01-03 KiCAD EDA files
    [sturmfront.kicad_pcb, sturmfront.sch]
2022-01-11 Initial firmware commit
    [configuration.h]
2022-01-11 Add sturmfront schematic
2022-01-26 Add wifi socket images
2022-01-26 Add prototyping and PCB images
2022-01-26 Add image of debugging the engineering prototype
2022-01-26 Add PNG of schematic for github pages
2022-01-26 Add circuit description
